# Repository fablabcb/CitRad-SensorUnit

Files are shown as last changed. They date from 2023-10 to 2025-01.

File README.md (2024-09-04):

# CitRad - Citizen Science Traffic Radar 

Here you find all the sources about how to build our traffic counter radar system. Find more about the project in general on our [project page](https://community.fablab-cottbus.de/t/ueber-das-cityradar-projekt/453). Discussions about the prototype development you find [here](https://community.fablab-cottbus.de/t/cityradar-teensy-prototyp/492/9). Also we have a separate discussion page about the [development of the casing](https://community.fablab-cottbus.de/t/gehaeusebau-fuer-die-radarsensorelektronik/507).

More details are in the [Software README]() and the [Hardware README](https://github.com/fablabcb/CityRadar/tree/main/Hardware#readme).

## Archive

In the beginning we started to develop a low noise amplifier for the radar module that we didn't need in the end. You find all about this in the [low-noise-amplifier branch](https://github.com/fablabcb/CityRadar/tree/low-noise-amplifier) and on the [discussion page in our forum](https://community.fablab-cottbus.de/t/citrad-elektronik-entwicklung/454)

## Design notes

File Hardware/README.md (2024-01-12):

# Bauanleitung Akkuvariante

## Teile

- Elektronik
  - [Teensy 4.0](https://www.pjrc.com/store/teensy40.html)
  - [Teensy Audio Board](https://www.pjrc.com/store/teensy3_audio.html)
  - [Innosent IPS-354 Radarmodul](https://www.innosent.de/radarsensoren/ips-354/) ([Handbuch](https://mm.digikey.com/Volume0/opasdata/d220001/medias/docus/2406/200730_Data%20Sheet_IPS-354_V1.5.pdf))
  - [isolierter DC-DC: ROE-3.305S](https://de.rs-online.com/web/p/dcdc-wandler/1392970)
  - [Akkupack](https://exp-tech.de/products/battery-lipo6600mah?_pos=33&_sid=1be852f75&_ss=r)
   - optional [TC4056](https://www.amazon.de/Aideepen-Lithium-Akku-Ladeplatine-Ladeger%C3%A4t-doppelten-Schutzfunktionen-Gr%C3%BCnes/dp/B0BZRT7Q6G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) Laderegler zum Laden der Batterie
  - SD-Karte nach Wahl
  - 40mm Kabel für Gnd des Radarmoduls
  - 40mm 2-Ader Kabel für Batteriestecker
  - Batteriestecker

- Gehäuse
  - [TRU COMPONENTS F3 Gehäuse](https://www.conrad.de/de/p/tru-components-f3-tc-6649456-universal-gehaeuse-115-x-90-x-55-abs-hellgrau-1-st-1662364.html)
  - [3D-Druck Halterung](https://community.fablab-cottbus.de/uploads/short-url/1HOEbMkdQxn1l1QFID4sH8OvwRe.stl)
  - [Lasercut Teile](https://community.fablab-cottbus.de/uploads/default/original/2X/0/07901a34dd58c6f2333bfa3191eb76f0abf1efdd.svg) zur Befestigung.
  - Velcro zur Befestigung des Akkus
  - Befestigungss  chrauben
    - 6x M4 für Einlegplatte und Seitenteile des Radarmoduls
    - 3x M3 für Befestigung der Platine

- Pfahlbefestigung
   - Lasercut Platte (enthält auch die Unterlegscheiben)
   - 4 x M5x10 für die Befestigungsplatte
   - 2x Velcro
   - 1x Kabelbinder

## Aufbau

### Platine vorbereiten

1. Teensy Vusb-Verbindung trennen (mit Messer). Danach einmal an USB anstecken und sicherstellen dass der Teensy nicht mehr von USB versorgt wird.
1. Knopfzellenbatterie an Teensy anlöten.
1. 14-Pin Pinleiste mit kurzer Seite in Audio Board einsetzen
1. Teensy auf die langen Stifte aufsetzen (Pins stehen über)
1. Pins auf der Audio Board Seite festlöten
1. von der Teensy Seite: 5V Pin und GND Pin (rechts und links vom USB) nach vorne biegen.
1. Batteriekabel an die überstehenden Pins von Gnd und 5V des Teensy löten.
1. Danach alle 14 Pins auch von der Teensy-Seite anlöten
1. Batteriestecker an Batteriekabel löten.
1. Die restlichen überlangen Pins können optional gekürzt werden.
1. DC-DC mit 3.3V und Gnd des Teensy verbinden (siehe Foto)
1. 6-Pin-Stecker mit langen Beinen anlöten:
    1. Pin 1 (Nummerierung wie am Radar-Modul) aus dem Stecker ziehen (wird nicht benötigt).
    1. Pin 5 und 6 umbiegen sodass sie in die line-in Anschlüsse des Audio Boards passen (siehe Foto).
    1. Enable (Pin 2) umbiegen und mit Pin 17 des Teensy verbinden (passt gerade so).
    1. Gnd (Pin 4) und Vcc (Pin 3) mit dem Output des DC-DC verbinden (siehe Foto). Hier muss man ca 4mm mit Lötzinn oder einem kurzen Draht überbrücken.
1. 4-Pin Stecker: GND (Pin 9) über kurzes Kabel mit Gnd am linein oder mic in verbinden.

### Radarmodul zusammen stecken

1. Radarmodul in 3D-Druck Halterung stecken (siehe Foto).
1. Teensy an 3D-Druck Halterung anschrauben (siehe Foto). Dabei die Stecker des Radarmoduls aufstecken.
1. 4-Pin Stecker am Radarmodul einstecken.
1. Lasercut Teile seitlich an das Radarmodul anschrauben.
1. SD-Karte in Audioboard einsetzen.

### Gehäuse vorbereiten

1. Grundplatte in Gehäuse schrauben.
1. Gewinde in Befestigungslöcher (Rückseite) schneiden.
1. Mastplatte mit M5-Schrauben und den Unterlegschrauben (im Lasercut Teil enthalten) an Rückseite anschrauben. 
1. Gummidichtung in Deckel einlegen (was zu lang ist abschneiden).

### Zusammenbau

1. Akku mit Kletterverschluss an Grundplatte befestigen.
1. Knopfzelle in Knopzellenhalter einsetzen.
1. Radarmodul mit Halterung in Schlitze in der Grundplatte stecken.
1. Teensy mit Batterie verbinden.

## Software installieren
1. Sketch drauf laden
2. Uhrzeit einstellen
3. Mit Processing überprüfen ob der Radarsensor richtig funktioniert

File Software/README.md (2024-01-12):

# Teensy Audio Board Prototype

This prototype works with the [IPS-354](https://media.digikey.com/pdf/Data%20Sheets/InnoSenT/200730_Data%20Sheet_IPS-354_V1.5.pdf) Radar Sensor from InnoSenT connected directly to the mic input of the [Teensy Audio Board](https://www.pjrc.com/store/teensy3_audio.html). The IPS-354 has a builtin gain of 27dB. The mic input of the audio board can regulate it's gain from 0 to 63dB. Together that's enough to detect cars, pedestrians and bicycles from the third floor of a building. When measured directly at the edge of the street the signal goes into clipping, so that the mic gain has to be set to about 55 to 58 dB. 

The teensy is programmed to continuously calculate a 1024 point FFT and transmit the data over Serial to the computer. The data are taken there by a [Processing](https://processing.org/) Script and visualized as a [waterfall diagram](https://en.wikipedia.org/wiki/Waterfall_plot). Additionally the Teensy calculates the frequency with highest amplitude which is optionally drawn as a line into the graph. This represents the mean speed of a moving object detected by the radar. 

The conversion from FFT bin to frequency is:

fft_bin_width = sample_rate/1024 = 44100 Hz/1024 = 43.0 Hz

The conversion from frequency to speed (at optimal angle, meaning the object comes directly onto the sensor) is:

speed = frequency/44

The Teensy also detects clipping with the `peak` function. If peak is returned as 1 the signal is in clipping. This is shown in the app as a green rectangle that turns red. With the <kbd>+</kbd> and <kbd>-</kbd> keys the gain can be regulated up or down to prevent clipping. Also the scale can be changed with the up and down arrows better see the lower speeds. You can also take a screenshot of the current view by pressing <kbd>s</kbd>.

Here a measurement done from 2m distance from the street edge. 

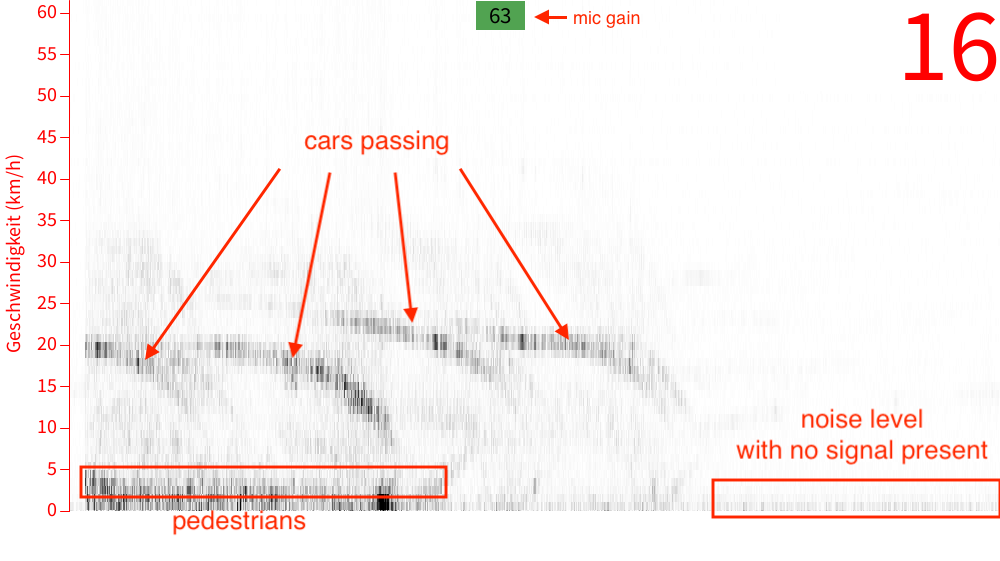
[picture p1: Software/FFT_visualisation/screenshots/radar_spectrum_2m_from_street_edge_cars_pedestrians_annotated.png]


Here a measurement with a pedestrian up close where arm and leg movement can be seen in the signal. Cars are on the opposite side of the street and hence with fainter signal:

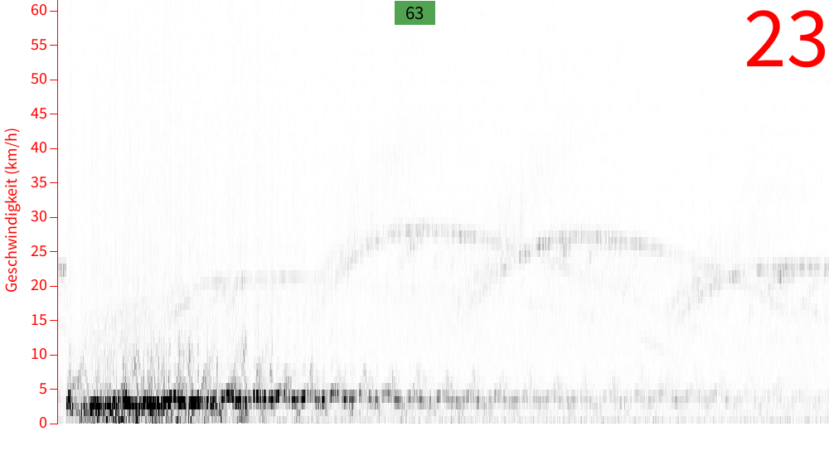
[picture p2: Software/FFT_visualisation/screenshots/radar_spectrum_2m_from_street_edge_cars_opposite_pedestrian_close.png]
pedestrian close


Here a measurement closer to the street with cars traveling both directions:	

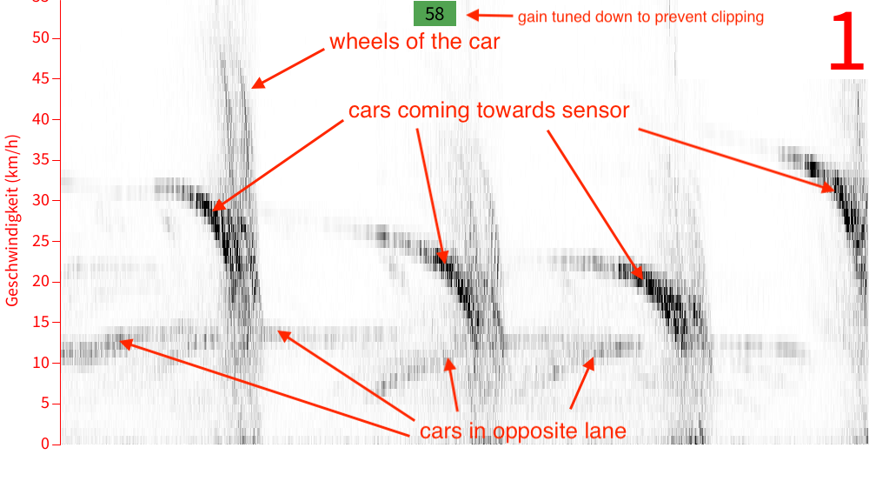
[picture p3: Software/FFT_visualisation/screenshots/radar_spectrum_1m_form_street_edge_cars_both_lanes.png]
cars both lanes


## Wiring

| IPS-354 | Audio Board | Teensy |
| --- | --- | --- |
| Pin 2 (enable) | - | Pin 22 |
| Pin 3 (Vcc) | - | Vcc |
| Pin 4 (Gnd) | Mic Gnd | Gnd |
| Pin 5 (signal I) | Mic | - |

## 32bit Audio Library

To get better input resulution we use a 32bit audio library that was forked from the original Teensy Audio library:

[OpenAudio_ArduinoLibrary](https://github.com/chipaudette/OpenAudio_ArduinoLibrary)

Similar to the original audio library it has a Design tool:

[OpenAudio_Design_Tool](http://www.janbob.com/electron/OpenAudio_Design_Tool/index.html)

## Serial

The teensy opens two serial connections over usb. The first one `Serial` is used for data transmission to the processing visualisation script. 
The second one `SerialUSB1` is used for debugging.

It is important to set the Arduino IDE to dual serial: "Tools > USB Type: Dual Serial".

More infos under https://github.com/TeensyUser/doc/wiki/Serial and https://www.pjrc.com/teensy/td_serial.html

## IQ FFT

The 32bit audio library supports complex FFT calculation with I and Q channel. The [IPS-354](https://media.digikey.com/pdf/Data%20Sheets/InnoSenT/200730_Data%20Sheet_IPS-354_V1.5.pdf) sends 
I and Q signals from which the direction of the radar signal can be derived. To record I and Q signal we have to use the linein input instead of the mic input. This has only 0-22dB gain 
instead of up to 63dB gain on the mic input. But it offers two channels that we need for the IQ signal. The input sensitivity seems enough for the IPS-354.

We have done a correction for I-Q imbalance after [this instruction](https://www.faculty.ece.vt.edu/swe/argus/iqbal.pdf).

We develop this type of data analysis in the [IQ-fft branch](https://github.com/fablabcb/CityRadar/tree/IQ-fft/Teensy_prototype). 

The wiring is as follows:

| IPS-354 | Audio Board | Teensy |
| --- | --- | --- |
| Pin 2 (enable) | - | Pin 22 |
| Pin 3 (Vcc) | - | Vcc |
| Pin 4 (Gnd) | Linein Gnd L| Gnd |
| Pin 5 (signal I) | Linein L | - |
| Pin 6 (signal Q) | Linein R | - |

## Writing to SD card

The program writes FFT data to the SD card (if present). The format is one 32bit unsigned integer timestamp in milliseconds since the start of the program
followed by 1024 times 32bit floats of the FFT bins in dBFS. This repeats for as long as the program was running.

At the beginning there is a file header containing:

- file_version (uint 2 bytes)
- timestamp (uint 4 bytes)
- fft_bins (uint 2 bytes)
- iq_measurement (bool 1 byte)
- sample_rate (uint 2 bytes)

In general every 12 milliseconds one dataset is written. Sometimes there seem to be hookups where there is longer times between datasets (up to 100 milliseconds).

The file `read_binary_file.R` shows how to read this dataset into R.

### SD noise problems

At the moment writing to SD creates noise in the data.

Some ideas how to tackle this:

- Some ideas from here: [How-to-avoid-noise-when-writing-to-the-microSD](https://forum.pjrc.com/threads/25326-How-to-avoid-noise-when-writing-to-the-microSD)
- change main clock speed -> didn't improve noise
- change slew rate of the pins: https://www.pjrc.com/teensy/IMXRT1060RM_rev2.pdf#page=695 with `IOMUXC_SW_PAD_CTL_PAD_GPIO_B0_00 = 0b0000'0000'0000'0000'0001'0000'1011'0000;`
- add condensators to buffer high Vcc demands
  - 10kOhm to buffer sensor input voltage didn't help
- use SD card of Teensy 4.1 instead of the audioshield. This itself doesn't improve. But maybe the SD pins to the audioboard should not be connected?
- pause data aquisition while writing to SD

## Real time clock

To add correct timestamps to the stored data we use the internal real time clock (RTC) of the Teensy. A coin cell battery needs to be connected to the VBat input 
to keep the internal RTC running. More on this here: [Teensy Time library explanation and examples](https://www.pjrc.com/teensy/td_libs_Time.html).

The Teensy uses the [Arduino time library](https://playground.arduino.cc/Code/Time/). 
Since at 44100 kHz we get a 1024 point FFT every 12 milliseconds a sub-second time resolution is needed.
The [millis function](https://www.arduino.cc/reference/en/language/functions/time/millis/) gives back milliseconds since start of the processor and can
complement the timestamp from the Time library. 

TimeSerial example under `File > Examples > Time > TimeSerial` shows how to set the rtc time via serial input.
Here is a forum Thread on [how to access the internal RTC in a Teensy 4.0](https://forum.pjrc.com/threads/60317-How-to-access-the-internal-RTC-in-a-Teensy-4-0).

From the Linux command line you can set the clock on the Teensy with:

```
date -u +T%s > /dev/ttyACM0
```
The command sends the letter "T" followed by the current time. Replace `ttyACM0` with your serial device name. 
`-u` sets the time as [Unix time](https://en.wikipedia.org/wiki/Unix_time).

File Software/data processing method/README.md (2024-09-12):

# CitRad Radar Sensor data processing method

We use R to prototype and test the data processing later to be implemented on the sensor unit itself. 

## Setup R environment:

Install R from [r-project.org](https://www.r-project.org/). Also we suggest using the [RStudio IDE](https://posit.co/downloads/).

Open the project by opening the `.Rproj` file in RStudio.

We use [renv](https://rstudio.github.io/renv/index.html) to keep track of package versions. Execute `renv::restore()` to install all packages recorded in `renv.lock`. Maybe you have to install renv first with `install.packages("renv")`.

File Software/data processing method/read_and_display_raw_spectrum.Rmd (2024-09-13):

---
title: CitRad - read and display raw spectrum data
---

```{r knitr settings, echo=F, include=F}
knitr::opts_chunk$set(echo=T, cache=F, warning =F, message = F, error = F)
```

Load the necessary libraries:

```{r libraries and helper functions}
library(plyr)
library(dplyr)
library(viridis)
library(lubridate)
source("functions.R")
```

## read data

To read the raw data use the `read_binary_file_8bit()` function located in `functions.R`. 

```{r read data, results='hide'}
filename <- "../../../data/SD-Card/2024-03-29_Nordring/rawdata_2024-3-29_12-8-50.BIN"
data_list <- read_binary_file_8bit(filename)
#rm(data, file_version, iq_measurement, n, num_fft_bins, size, start_time, timestamps, sample_rate)
attach(data_list)
```

The `attach()` command puts all variables in data_list in the global environment.

## conversion between frequency and speed

The FFT bins go from 1 to 1024. Bin 512 is 0 km/h. The upper bins represent positive speeds, lower bins negative speed (movement in the opposite direction). The conversion factor between frequency and speed is the following:

$$\frac{sample\_rate}{1024}/44.0 \approx 0.266$$
with $sample\_rate = `r sample_rate`$

```{r speed conversion, echo=T}
speed_conversion = (sample_rate/1024)/44.0
speeds <- (1:1024-512) * speed_conversion
```

In preparation for the plots we also do some timestamp conversion:

```{r timestamp conversion}
timestamps_date <- start_time + milliseconds(timestamps)
timestamp_minutes = timestamps/1000/60
```

# plot spectrum

```{r plot with timestamp}
index <- 19585+0:1000
image(timestamp_minutes[index], speeds,  data[index,], col=magma(100), main="spectrum")
```

To speed up the generation of the spectrum plot (especially for large timeframes) we can use the option `useRaster = T`:

```{r plot faster with index}
image(index, speeds,  data[index,], col=magma(100), useRaster = T, main="spectrum")
```

Since `useRaster` needs a regular x-axis we can't use the timestamp, since that one is a bit irregular depending on the processing speed of the Teensy:

```{r timestamp irregularities}
diff(timestamps) %>% unique %>% sort
```

To add back some sensible x-axis:

```{r plot with tick labels}
tick_positions <- seq(min(index), max(index), length.out=10)
tick_labels <- (start_time + minutes(round(timestamp_minutes[tick_positions]))) %>% with_tz("CET") %>%
  format("%Y-%m-%d\n%H:%M:%S %Z") %>% paste(., "\n", round(tick_positions))

image(index, speeds,  data[index,], col=magma(100), useRaster = T, xaxt="n", xlab="", main="spectrum")
axis(1, tick_positions, tick_labels, mgp=c(4, 2.5, 0))
```

We can also limit the speeds to the expected range and add some grid lines:

```{r speed selection and grid lines}
speed_selection <- which(abs(speeds)<=70)
image(index, speeds[speed_selection],  data[index,speed_selection], col=magma(100), useRaster = T, xaxt="n", xlab="", main="spectrum")
axis(1, tick_positions, tick_labels, mgp=c(4, 2.5, 0))
abline(h=-7:7*10)
```

# write plot to file:

We create a graphics folder first:

```{r create graphics folder}
dir.create("Grafiken")
```

And then render a graphic for the whole timeline into a png file:

```{r export png}
system.time({ # tells us the processing time it took
  
# calculate pixel width with 200 pixels per minute:
timerange_minutes <- diff(range(timestamp_minutes))
pixel_width <-  round(timerange_minutes) * 200

# pepare axis with 1 tick per minute:
index <- 1:length(timestamps)
tick_positions <- seq(min(index), max(index), length.out=timerange_minutes)
tick_labels <- (start_time + minutes(round(timestamp_minutes[tick_positions]))) %>% with_tz("CET") %>%
  format("%Y-%m-%d\n%H:%M:%S %Z") %>% paste(., "\n", round(tick_positions))

filename = paste0("./Grafiken/", as.numeric(Sys.time()), ".png")
# open graphic device:
png(filename, height = 500, width = pixel_width)

# create graphic
image(index, speeds[speed_selection],  data[index,speed_selection], col=magma(100), useRaster = T, xaxt="n", xlab="", main="spectrum")
axis(1, tick_positions, tick_labels, mgp=c(4, 2.5, 0))
abline(h=-7:7*10)

# close graphic device
dev.off()

})
```

In my experience the fastest way to display big spectrum image files is in the browser (like Firefox or Chrome).

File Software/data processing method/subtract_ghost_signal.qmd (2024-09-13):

---
title: Citrad - tests to subtract ghost signal
format: 
  revealjs:
    css: style.css
    auto-stretch: false
    
output: 
  revealjs::revealjs_presentation:
    code_folding: hide
---

## ghost signal

Whenever the sensor detects a forward signal it also detects a signal in the opposite direction. Mirroring and subtracting the spectrum is one approach to deal with this. It seemed to work for the measurements we made at BTU location. But doesn't work at the Nordring location. There might be differences in the Q-I balance settings between those measurements. This has still to be validated.

```{r knitr settings, echo=T, include=F}
knitr::opts_chunk$set(echo=F, cache=F, warning =F, message = F, error = F)
```

```{r libraries}
library(plyr)
library(dplyr)
library(dygraphs)
library(viridis)
library(lubridate)

source("functions.R")
```

# BTU

```{r read BTU data, results="hide"}
filename <- "../../../data/SD-Card/2023-12-07/rawdata_2023-12-6_19-41-12.BIN"
data_list <- read_binary_file_8bit(filename)
attach(data_list)
timestamps_date <- start_time + milliseconds(timestamps)
timestamp_minutes = timestamps/1000/60
speed_conversion = (sample_rate/1024)/44.0
speeds <- (1:1024-512) * speed_conversion
```

## spectrum

```{r BTU plot with different subtractions, fig.subcap="The signal looks mirrored around 0, but the ghost signal on the opposite side is a bit weaker. This timeframe actually contains 3 Targets (one in opposite direction)."}
s = 971000
index <- 971000 + 0:1000

image(index, speeds,  data[index,], col=magma(100), useRaster = T, family="Arial")
```

## spectrum - 50% mirror

```{r BTU plot with different subtractions 2, fig.subcap="Subtracting 50% of the mirrored spectrum removes a lot of the oscillating noise patterns and some of the ghost reverse signals."}
image(index, speeds,  data[index,]-.5*data[index,c(1023:1,1)], col=magma(100), useRaster = T, family="Arial")
```

## spectrum - 100% mirror

```{r BTU plot with different subtractions 3, fig.subcap="This seems to remove nearly all noise. The ghost signal now has negative values. Additionally the line around 0 km/h disappears and values are around 0."}
image(index, speeds,  data[index,]-1*data[index,c(1023:1,1)], col=magma(100), useRaster = T, family="Arial")
```

## spectrum - 100% mirror, <0 set to 0

```{r BTU plot with different subtractions 4, fig.subcap="Removing all negative values leaves only the signal clearly highlighted. But some noise spikes are pretty bright."}
mirror_subtracted <- (data[index,]-1*data[index,c(1023:1,1)])

mirror_subtracted[mirror_subtracted<0] = 0

image(index, speeds, mirror_subtracted , col=magma(100), zlim=c(0,30), useRaster = T, family="Arial")
```

```{r BTU export png, eval=F, echo=F}
system.time({ # tells us the processing time it took
  
index <- 4*226104+1:226104
# calculate pixel width with 200 pixels per minute:
timerange_minutes <- diff(range(timestamp_minutes[index]))
pixel_width <-  round(timerange_minutes) * 200

# pepare axis with 1 tick per minute:
tick_positions <- seq(min(index), max(index), length.out=timerange_minutes)
tick_labels <- (start_time + minutes(round(timestamp_minutes[tick_positions]))) %>% with_tz("CET") %>%
  format("%Y-%m-%d\n%H:%M:%S %Z") %>% paste(., "\n", round(tick_positions))

speed_selection <- which(abs(speeds)<=70)

filename = paste0("./Grafiken/BTU_", as.numeric(Sys.time()), ".png")
# open graphic device:
png(filename, height = 500, width = pixel_width)

# create graphic
image(index, speeds,  data[index,] - data[index,c(1023:1,1)], col=magma(100), useRaster = T, xaxt="n", xlab="", main="BTU")
axis(1, tick_positions, tick_labels, mgp=c(4, 2.5, 0))
#abline(h=-7:7*10)

# close graphic device
dev.off()

})
```

```{r, echo=F}
detach(data_list)
rm(data_list)
```

# Nordring

```{r read Nordring data, results="hide"}
filename <- "../../../data/SD-Card/2024-03-29_Nordring/rawdata_2024-3-29_12-8-50.BIN"
data_list <- read_binary_file_8bit(filename)
#rm(data, file_version, iq_measurement, n, num_fft_bins, size, start_time, timestamps, sample_rate)
attach(data_list)
timestamps_date <- start_time + milliseconds(timestamps)
timestamp_minutes = timestamps/1000/60
```

```{r calc speeds}
speed_conversion = (sample_rate/1024)/44.0
speeds <- (1:1024-512) * speed_conversion
```

## spectrum

```{r Nordring plot with different subtractions, fig.subcap="Multiple targets in this time window."}
index <- 19585+0:1000
spectrum_mirror_subtracted <- data[index,] - .5*data[index,c(1023:1,1)]

image(index, speeds,  data[index,], col=magma(100), useRaster = T)
```

## spectrum - 50% mirrored

```{r Nordring plot with different subtractions2, fig.subcap="Subtracting with 50% of the mirrored spectrum removes some of the ghost reverse signals, but also makes the real signal weaker in relation to the noise (noise gets brigther)."}
image(index, speeds,  spectrum_mirror_subtracted, col=magma(100), useRaster = T)
```

## spectrum - 100% mirrored

```{r Nordring plot with different subtractions3, fig.subcap="Subtracting with 100% of the mirrored spectrum hides the signal completely."}
spectrum_mirror_subtracted <- data[index,] - 1*data[index,c(1023:1,1)]
image(index, speeds,  spectrum_mirror_subtracted, col=magma(100), useRaster = T)
```

## spectrum - 100% mirrored, < 0 set to 0

```{r Nordring plot with different subtractions4, fig.subcap="no signal visible"}
spectrum_mirror_subtracted <- data[index,] - 1*data[index,c(1023:1,1)]
spectrum_mirror_subtracted[spectrum_mirror_subtracted<0] = 0
image(index, speeds,  spectrum_mirror_subtracted, col=magma(100), useRaster = T)
```

```{r Nordring export png, eval=F, echo=F}
system.time({ # tells us the processing time it took
  
# calculate pixel width with 200 pixels per minute:
timerange_minutes <- diff(range(timestamp_minutes))
pixel_width <-  round(timerange_minutes) * 200

# pepare axis with 1 tick per minute:
index <- 1:length(timestamps)
tick_positions <- seq(min(index), max(index), length.out=timerange_minutes)
tick_labels <- (start_time + minutes(round(timestamp_minutes[tick_positions]))) %>% with_tz("CET") %>%
  format("%Y-%m-%d\n%H:%M:%S %Z") %>% paste(., "\n", round(tick_positions))

filename = paste0("./Grafiken/Nordring_", as.numeric(Sys.time()), ".png")
# open graphic device:
png(filename, height = 500, width = pixel_width)

# create graphic
image(index, speeds,  data[index,], col=magma(100), useRaster = T, xaxt="n", xlab="", main="Nordring")
axis(1, tick_positions, tick_labels, mgp=c(4, 2.5, 0))
#abline(h=-7:7*10)

# close graphic device
dev.off()

})
```

```{r detach, results="hide"}
detach(data_list)
rm(data_list)
```

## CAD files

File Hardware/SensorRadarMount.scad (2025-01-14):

mainH = 12; // main body height
mainD = 45.9; // main body depth
mainW = 17.78 * 2; // main body width
roundingD = 6; // depth of the front/back rounding thingy
roundingHoleD = 2.8; // diameter of the back/front holes

sensorD = 44.3; // outer depth of the sensor plate
sensorW = 30.3; // outer width of the sensor plate
sensorFullSizeH = 3; // depth of the cutout for the sensor plate
sensorLipW = 1; // width of the lip for the sensor to rest on
sensorFullH = sensorFullSizeH + 6; // depth of the entire sensor cutout

smallSlotW = 12; // width of the small slot
smallSlotX = 10.5; // x offset (from outer edge)
bigSlotW = 17; // width of the big slot
bigSlotX = 8; // x offset (from outer edge)
sensorSlotD = 4; // depth of the header slots for the sensors

$fn=50;
e=0.01;

// xz-origin: center of the hole
module SideThingy()
{
    difference()
    {
        union()
        {
            cube([mainW/2,roundingD,mainH]);
            translate([0,0,mainH/2]) rotate([-90,0,0]) cylinder(d=mainH, h=roundingD);
        }
        
        translate([0,0,mainH/2]) rotate([-90,0,0]) cylinder(d=roundingHoleD, h=roundingD+e);
    }
}

module CompleteHolder()
{
    translate([0,-mainD/2,0]) difference() 
    {
        // main body
        cube([mainW, mainD, mainH]);
        // flat sensor part cutoff
        translate([1.36,(mainD-sensorD)/2,0]) cube([sensorW, sensorD, sensorFullSizeH]);
        // round sensor part cutoff
        translate([1.36+sensorLipW,(mainD-sensorD)/2+sensorLipW,0])
            cube([sensorW-2*sensorLipW, sensorD-2*sensorLipW, sensorFullH]);
        
        // small header slot
        translate([smallSlotX,sensorLipW+sensorD-sensorSlotD,-1]) cube([smallSlotW,sensorSlotD,99*mainH]);
        // big slot and push-through area
        translate([bigSlotX,sensorLipW,-1]) cube([bigSlotW,sensorD-10-sensorSlotD,99*mainH]);
        // holes
        hR=1.4;
        holes=[[1.9+hR,5.8+hR],[mainW-1.9-hR,5.8+hR],[14.6+hR,mainD-7.07-hR]];
        for(h=holes)
            translate([h[0],h[1],mainH-3]) cylinder(r=1.4, h=3+e);
        // groves for teensy pins
        for(y=[12.8,12.8+15.24])
            translate([0,y,mainH]) rotate([0,90,0]) cylinder(r=2, h=mainW, $fn=7);
        
        translate([mainW*0.73,mainD/2-5,mainH-1]) linear_extrude(1) text("v2",size=6);
    }
    
    translate([mainW/2,0,0])
    {
        translate([0,mainD/2,0]) SideThingy();
        mirror([0,1,0])
            translate([0,mainD/2,0]) SideThingy();
    }
}

CompleteHolder();

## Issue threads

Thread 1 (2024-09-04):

Auswertemethode erklären/dokumentieren

nFrechen, 2024-09-04:
Ich habe die bisherige Auswertemethode in R schon halb dokumentiert und mit Grafiken nachvollziehbar gemacht. Das müsste ich noch zu Ende bringen und die Verständlichkeit testen.

nFrechen, 2024-09-12:
In einem ersten Schritt habe ich dokumentiert wie man die Rohdaten einliest und das Spektrum mit R visualisiert: #[8b3c7b8](https://github.com/fablabcb/CitRad-SensorUnit/commit/8b3c7b8aca13ac50723f8f669568a57b6cc04ff8)

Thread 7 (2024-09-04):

kleinere Raw-Dateien schreiben

nFrechen, 2024-09-04:
z.B. Stündlich neue Dateien anlegen damit man keine 4GB Dateien einlesen muss

thorondev, 2024-09-22:
Nach je einer Stunde wird nun eine neue Datei geöffnet.

nFrechen, 2024-10-28:
Die start_time wird in die Datei geschreiben aber die millis werden nicht zurück gesetzt beim Erstellen einer neuen Datei. Wenn man nun versucht die Zeit zu rekonstruieren als start_time + millis hat man einen Zeitversatz.

nFrechen, 2024-10-28:
Ok, kann man beheben indem man den ersten gespeicherten millisecond Wert von allen Zeitstempeln abzieht.

thorondev, 2024-10-30:
Ja, das ist immer die Zeit, seit der der Sensor läuft und damit muss man das sowieso immer machen, um auf die korrekte Zeit zu kommen. Da die Datei erst angelegt wird, wenn der erste Datensatz geschrieben wird, entspricht der erste Zeitstempel der Erstellzeit der Datei.

Closed 2025-01-03.

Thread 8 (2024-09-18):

low battery detection

nFrechen, 2024-09-18:
Problem:

wenn die Akkuspannung niedrig ist geht der Teensy irgendwann aus, startet aber eventuell mehrmals nochmal neu wenn die Akkuspannung sich regeneriert (z.B. durch Temperaturschwankungen). Ergebnis: mehrere kleine Dateien mit neuen Messungen. Eventuell kann auch die SD-Karte kaputt gehen wenn der Teensy immer wieder startet.

Idee:

Batteriespannung messen und beim boot testen ob Spannung zu niedrig und in deep-sleep gehen.

thorondev, 2025-01-03:
Ich habe z.B. das hier gefunden, aber das übersteigt meine Elektronikkentnisse: https://forum.pjrc.com/index.php?threads/how-measure-battery-voltage.43430/

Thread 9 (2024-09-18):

Dateinamen (Zeitstempel) wenn RTC nicht arbeitet

nFrechen, 2024-09-18:
Wenn die RTC versagt (oder die Knopfzelle nicht drin ist) und der Teensy von "Tag 0" startet, wie vermeidet man dass Dateien überschrieben werden?

Idee:

Dateien durchnummerieren (d.h. checken ob schon andere Dateien da sind).

Closed 2024-09-22.

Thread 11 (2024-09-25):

smoothing

nFrechen, 2024-09-25:
Ich muss hier nochmal was meine Gedanken sortieren:

In der Auswertung werden wir an mehreren Stellen eine Glättung der Messwerte brauchen. Ein laufendes Mittel können wir mit drei verschiedenen Komplexitätsstufen umsetzen:

## 1. vereinfachtes Mittel

`runmean[i] = ((n-1) * runmean[i-1] + x[i])/n`

Hier braucht man keinen Array mit Werten vorhalten, sondern nur das letzte Mittel `runmean[i-1]`. Der neue Messwert `x[i]` wird auf das letzte Mittel drauf gerechnet mit einer Gewichtung (z.B. 1) während das vorige Mittel mit Gewichtung 99 eingeht. Zum Schluss wird alles durch n=100 geteilt.

Diese Berechnung ist mathematisch nicht 100% korrekt, da der Einfluss früher Werte nie ganz aus dem Mittelwert verschwindet. Allerdings funktioniert es ausreichend gut. Nachteil ist aber, dass die Methode nicht symmetrisch arbeitet.

## 2. echtes laufendes Mittel aber ohne bzw. mit Rechteck-Kernel

Hier muss ein Array aus Werten mitgeführt werden (z.B. die letzen 100 Werte). Jeder neue Messwert wird dem Array hinzugefügt während der älteste Wert aus dem Array gelöscht wird. Anschließend wird der Mittelwert über das Array berechnet. Da die Werte im Array nicht gewichtet werden (ohne Kernel), kann das Array als Ringspeicher geführt werden. Es wird also immer der älteste Wert mit dem neuesten überschrieben ohne die anderen Werte anzufassen.

Alle Werte mit gleicher Wichtung in das gleitende Mittel eingehen zu lassen entspricht einem Rechteck-Kernel. Durch den Rechteck-Kernel kann das Ergebnis immer noch scharfe Sprünge aufweisen, auch wenn die Amplitude abgeschwächt wird. Der Rechteck-Kernel bewirkt auch dass Peaks zu Plateaus ohne definierte Spitze werden. Das ist ungünstig wenn man die Spitze finden möchte. Daher die dritte Methode:

## 3. laufendes Mittel mit Gauß-Kernel

Wenn man die Mittelwert-Berechnung noch mit einer Gewichtung machen möchte (z.B. ein Gauß-Kernel), ist die Reihenfolge der Werte im Array relevant. Hier könnte man trotzdem noch mit einem Ringspeicher arbeiten, wenn man den Kernel entsprechend verschiebt. Ansonsten muss man mit jedem neuen Eintrag die anderen Werte im Array in ihrer Position nach vorne schieben.

Der Gauß-Kernel bewirkt dass Werte am Rande des Glättungsfensters weniger Einfluss auf den Mittelwert haben. Dadurch bekommt alles einen smoothen Übergang.  Der Gauß-Kernel erhält aber trotzdem größere Peaks die in den Daten enthalten sind.

thorondev, 2024-10-30:
Wir haben uns jetzt auf ein Hann-Fenster verständigt und das ist implementiert. Damit kann das hier geschlossen werden

Closed 2025-01-03.

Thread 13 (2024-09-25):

Gauß Kernel Glättung

nFrechen, 2024-09-25:
Für die Auto-Trigger-Berechnung brauche ich eine Glättung die zeitlich symmetrisch ist, also genauso viel Werte aus der Vergangenheit wie aus der Zukunft verrechnet. D.h man müsste n Werte als Array vorhalten und die Berechnung erst machen wenn n Werte aufgezeichnet wurden. Das Ergebnis kann man dann erst speichern wenn genug Werte aufgelaufen sind mit dem Zeitstempel um (n-1)/2 versetzt.  Von daher müsste  man das eventuell in eine zweite csv-Datei speichern oder in der schon existierenden CSV-Datei kenntlich machen dass der Wert um (n-1)/2 zeitlich verschoben ist.

$$w(i)=e^{-\frac{1}{2} \left ( \frac{i-(n-1)/2}{\sigma (n-1)/2} \right)^{2}}$$

mit $\sigma = 1/4$.
$i$ ist der index im Fenster.

n konfigurierbar. Im Moment rechne ich mit n=31. Nur ungerades n verwenden.

Das Fenster müsste man beim booten vorberechnen können und dann als Array vorhalten.

Wir hatten darüber diskutiert wie man das ganze mit einem Ringspeicher umsetzen kann.

Ergebnis als `car_trigger_signal` benennen. Eingabewert n als `car_trigger_signal_smoothing_factor` konfigurierbar machen.

nFrechen, 2024-09-25:
Noch besser wäre das [Hann-Fenster](https://de.wikipedia.org/wiki/Fensterfunktion#von-Hann-Fenster)

$$ w(i)={\frac {1}{2}}\left[1-\cos \left({\frac {2\pi i}{n-1}}\right)\right]$$

thorondev, 2024-10-01:
Config Value: "carTriggerSignalSmoothingFactor"

thorondev, 2024-10-01:
csv headers for new outputs (car_trigger_signal and dynamic_noise_level) now contain the N as a suffix.

Closed 2024-10-01.

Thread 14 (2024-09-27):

weitere Datenauswertung

nFrechen, 2024-09-27:
Ich habe die Auswertemethode nun in [Software/data processing method/data_processing_method.Rmd](https://github.com/fablabcb/CitRad-SensorUnit/blob/main/Software/data%20processing%20method/data_processing_method.Rmd) beschrieben.

Zu beachten in R:

- Der Array Index beginnt bei 1 und nicht bei 0
- Wenn `v` ein Vektor ist dann  kann man in R `v*2` rechnen, wodurch jedes Element im Array mit 2 multipliziert wird. Genauso kann man die Elemente von zwei gleich langen Vektoren Element zu Element miteinander verrechnen mit `v*w`. Man braucht hier also keine Schleife.
- `apply` Funktionen arbeiten ähnlich wie `map` Funktionen in anderen Sprachen. Damit kann man z.B. eine Matrix in Zeilen zerschneiden und eine Funktion auf jede Zeile anwenden.

Am besten gehen wir gemeinsam durch den Code und überlegen wie wir das Stück für Stück umsetzen können.

thorondev, 2024-10-30:
Aktueller Stand liegt auf dem Develop.

Closed 2024-10-30.

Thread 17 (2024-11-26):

timestamp Sprünge

nFrechen, 2024-11-26:
Der Zeitstempel in den Rohdaten zeigt manchmal Sprünge. Auf jeden Fall immer dann wenn intensiv gerechnet wird. Manchmal aber auch zwischendurch. Die Sprünge zwischendurch korrelieren mit Störsignalen die im Spektrum zu sehen sind (siehe Grafik unten). Das kann gut sein dass der Teensy da irgendwas macht was sowohl das Störsignal wie auch die Zeitverzögerung erzeugt. Ist die Frage ob man da rauskriegen kann was da passiert. Wenn das Störsignal im Spektrum verschwindet wäre schon gut.

Zu den rechen- bzw. schreibintensiven Zeiten könnte man vielleicht den Zeitstempel direkt generieren wenn die Daten von der FFT übernommen werden und nicht erst am Ende der Berechnung. Ich hab mir noch nicht angeschaut wie das zur Zeit umgesetzt ist.

Die Schwarze Linie ist die Zeitdifferenz zwischen zwei Zeitstempeln (in Millisekunden). Oft sieht es aus als würde der längere Zeitabstand durch einen entsprechend kürzeren ausgeglichen. Manchmal aber auch nicht.
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

thorondev, 2024-11-26:
Der Zeitstempel wird bisher tatsächlich nach der Berechnung ermittelt. Das ist natürlich etwas ungünstig und kann ich ändern. Ansonsten sehe ich in den Sprüngen kein größeres Problem.

nFrechen, 2024-11-27:
Dann kannst du den Zeitstempel ja direkt nach der FFT speichern. Das wäre ja eine einfache Maßnahme.

Das mit dem regelmäßigen Störsignal kriegt man wahrscheinlich nicht so leicht raus warum das passiert. Das wäre eher interessant wegen dem Störsignal selbst und nicht wegen dem Zeitversatz. Der Zeitversatz ist nur ein Hinweis darauf dass der Teensy da irgendwas rechnet was ihn aufhält.

Das Thema kommt auf weil ich mich gerade damit beschäftige wie man noch die Fahrzeuglänge aus dem Signal berechnen kann. Da wäre ein Zeitversatz im Signal ungünstig. Aber ich hab bisher auch nur grobe Ideen dazu. Vielleicht ist es auch kein Problem.

thorondev, 2025-01-03:
fixed in 9f67bfd804535d440e483ddbcd22a1cdf3078162

Closed 2025-01-03.

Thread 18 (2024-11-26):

Zeitstempel Versatz zwischen csv- (car) und bin-Datei

nFrechen, 2024-11-26:
Wenn ich die Zeitstempel aus der cars csv Datei einlese und diesen Zeistempel nutze um das Spektrum aus der bin Datei abzufragen komme ich nicht exakt zu dem Zeitpunkt wo das Auto vorbei gefahren ist. Der Zeitvesatz ist manchmal länger, manchmal kürzer (siehe Beispiele unten).

Der Abstand variiert auch innerhalb einer Datei. Von daher denke ich nicht dass ich da was falsch einlese.

Hast du eine Idee woher das kommen könnte?

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

thorondev, 2024-11-26:
Der Zeitstempel in der Car-CSV gibt an, wann das Signal als ein Auto erkannt wurde und nicht, wann genau ein Peak in der meanAmplitude vorlag.

Du kannst auf jeden Fall also schonmal die Hann-Fensterbreite abziehen, weil das ja später erst ausgewertet werden kann. Und dann ist natürlich jedes Signal unterschiedlich lang - das fließt auch wieder mit ein.
Wenn du die Zuordnung tatsächlich brauchst, muss das hinzugefügt werden. Der Sensor merkt sich die vergangenen Zeitstempel bisher nicht.

thorondev, 2025-01-07:
Mit Dateiversion 3 ist der Zeitstempel Car-CSV-Datei nicht länger der Zeitpunkt, wann die Erkennung gespeichert wurde, sondern wann das Trigger-Signal in den Daten erkannt wurde. Damit kann man jetzt den Zeitstempel suchen, die Hann-Fensterbreite abziehen und ist an der richtigen Position.

thorondev, 2025-02-03:
Mit Dateiversion 4 ist im Header jeweils ein TimeOffset vorhanden. Siehe FileFormats.md.

Closed 2025-02-03.

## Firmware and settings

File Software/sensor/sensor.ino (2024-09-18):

#include "AudioSystem.h"
#include "Config.h"
#include "FileWriter.hpp"
#include "SerialIO.hpp"
#include "functions.h"

#include <SerialFlash.h>
#include <Wire.h>
#include <utility/imxrt_hw.h>

AudioSystem audio;
AudioSystem::Results audioResults; // global to optimize for speed
Config config;

FileWriter fileWriter;
SerialIO serialIO;

bool canWriteData = false;

void setup()
{
    setSyncProvider(getTeensy3Time);
    setI2SFreq(config.audio.sample_rate);

    // TODO maybe move to audio
    pinMode(PIN_A3, OUTPUT); // A3=17, A8=22, A4=18
    digitalWrite(PIN_A4, LOW);

    audio.setup(config.audio, config.max_pedestrian_speed, config.send_max_speed);

    // TODO this seems to be a get&set to and from the same data point?
    // setTime(Teensy3Clock.get());
    // timestamp = now();
    {
        time_t timestamp = Teensy3Clock.get();
        setTime(timestamp);
    }

    // wait max 5s for serial connection
    {
        Serial.begin(9600);
        int counter = 5;
        while(counter > 0 && !Serial)
        {
            delay(1000);
            counter--;
        }
        Serial.println("Hello Citizen Radar");
    }

    fileWriter.setupSpi();

    if(fileWriter.setupSdCard())
    {
        canWriteData = true;
        Serial.println("SD card initialized");
    }
    else
        Serial.println("Unable to access the SD card");
}

void loop()
{
    if(not canWriteData)
    {
        if(fileWriter.setupSdCard())
        {
            canWriteData = true;
            Serial.println("SD card initialized");
        }

        delay(1000);
        return;
    }

    if(not audio.hasData())
    {
        delay(1);
        return;
    }

    bool sendOutput = false; // send output over serial - attention: this is only send once and needs to be preserved
    // and thus might be better put into global state or something

    serialIO.processInputs(config.audio, sendOutput);
    if(config.audio.hasChanges)
    {
        audio.updateIQ(config.audio);
        config.audio.hasChanges = false;
    }

    // elapsed time since start of sensor in milliseconds
    audioResults.timestamp = millis();
    audio.processData(audioResults);

    if(config.writeDataToSdCard)
    {
        if(config.writeRawData)
            fileWriter.writeRawData(audioResults, config.write8bit, config);

        if(config.writeCsvData)
            fileWriter.writeCsvData(audioResults, config);

        // SerialUSB1.print("csv sd write time: ");
        // SerialUSB1.println(millis()-time_millis);
    }

    if(sendOutput)
        serialIO.sendOutput(audioResults, audio, config);
}

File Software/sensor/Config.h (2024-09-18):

#ifndef CONFIG_H
#define CONFIG_H

#include "AudioSystem.h"

#include <cstddef>
#include <string>

struct Config
{
    AudioSystem::Config audio;

    const float max_pedestrian_speed = 10.0; // m/s; speed under which signals are detected as pedestrians
    const float send_max_speed = 500;        // don't send (and store) spectral data higher than this speed
    const float TRIGGER_AMPLITUDE = 100;     // trigger threshold for mean amplitude to signify a car passing by
    const long COOL_DOWN_PERIOD = 1000;      // cool down period for trigger signal in milliseconds

    const bool writeDataToSdCard = true; // write data to SD card?
    const bool write8bit = true;         // write data as 8bit binary (to save disk space)
    const bool writeRawData = true;      // write raw spectral data to SD?
    const bool writeCsvData = true;      // write calculated metrix to csv table?

    const bool splitLargeFiles = true;     // if true, the raw and csv files will be split after each given timespan
    const size_t maxSecondsPerFile = 3600; // used if splitLargeFiles is true
    const String filePrefix;               // file name prefix (containing id and stuff)

    Config()
        : filePrefix("test_unit_")
    {}
};

#endif

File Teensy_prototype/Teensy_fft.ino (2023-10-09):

#include <Audio.h>
#include <Wire.h>
#include <SPI.h>
#include <SD.h>
#include <SerialFlash.h>
#include <utility/imxrt_hw.h>

void setI2SFreq(int freq) {
  // PLL between 27*24 = 648MHz und 54*24=1296MHz
  int n1 = 4; //SAI prescaler 4 => (n1*n2) = multiple of 4
  int n2 = 1 + (24000000 * 27) / (freq * 256 * n1);
  double C = ((double)freq * 256 * n1 * n2) / 24000000;
  int c0 = C;
  int c2 = 10000;
  int c1 = C * c2 - (c0 * c2);
  set_audioClock(c0, c1, c2, true);
  CCM_CS1CDR = (CCM_CS1CDR & ~(CCM_CS1CDR_SAI1_CLK_PRED_MASK | CCM_CS1CDR_SAI1_CLK_PODF_MASK))
       | CCM_CS1CDR_SAI1_CLK_PRED(n1-1) // &0x07
       | CCM_CS1CDR_SAI1_CLK_PODF(n2-1); // &0x3f 
}

const int sample_rate = 44100;
uint16_t max_amplitude;                   //highest signal in spectrum              
uint16_t max_freq_Index;
float speed_conversion = (sample_rate/1024)/44.0;
int input;
int mic_gain = 16;

AudioAnalyzeFFT1024      fft1024;      
AudioAmplifier           amp1;           
AudioAnalyzePeak         peak1;          
AudioMixer4              mixer;

AudioInputI2S            mic;           
AudioOutputI2S           headphone;           
AudioConnection          patchCord1(mic, 0, mixer, 0);
AudioControlSGTL5000     sgtl5000_1;     
AudioConnection          patchCord3(mic, amp1);
AudioConnection          patchCord4(amp1, 0, fft1024, 0);
AudioConnection          patchCord5(mixer, 0, peak1, 0);
AudioConnection          patchCord6(mixer, 0, headphone, 0);
AudioConnection          patchCord7(mixer, 0, headphone, 1);


void setup() {
  setI2SFreq(sample_rate);

  // Audio connections require memory to work.  For more
  // detailed information, see the MemoryAndCpuUsage example
  AudioMemory(60);

  // Enable the audio shield, select input, and enable output
  sgtl5000_1.enable();
  sgtl5000_1.inputSelect(AUDIO_INPUT_MIC);
  sgtl5000_1.micGain(mic_gain); 
  //sgtl5000_1.lineInLevel(0);
  sgtl5000_1.volume(.5);

  amp1.gain(1);

  fft1024.windowFunction(AudioWindowHanning1024);

  pinMode(PIN_A8, OUTPUT);
  digitalWrite(PIN_A8, LOW); 

  Serial.begin(1000000);
}


void loop() {

  if (Serial.available() > 0) {
    input = Serial.read();

    if(input==0){
      mic_gain--;
    }
    if(input==1){
      mic_gain++;
    }
    mic_gain = max(0, min(63, mic_gain));
    sgtl5000_1.micGain(mic_gain);
  }

  uint32_t i;
  // uint16_t test[51];
  // for(i = 0; i <= 50; i++){
  //   if(i==10){
  //     test[i] = 40;
  //   }else{
  //     test[i] = i;
  //   }
    
  // }


  if(fft1024.available())
  {
    // output spectrum
    for(i = 0; i <= 511; i++)
    {
      Serial.print((int16_t)(fft1024.read(i) * 1000));

      
      //Serial.write((byte*)&test, sizeof(test));

      // Serial.write(lowByte(test));
      // Serial.write(highByte(test));

      Serial.print(",");
    }
                            
    // detect highest frequency
    max_amplitude = 0;
    max_freq_Index = 0;

    for(i = 0; i < 512; i++) {    
      if ((fft1024.output[i] > 5) & (fft1024.output[i] > max_amplitude)) {
        max_amplitude = fft1024.output[i];        //remember highest amplitude
        max_freq_Index = i;                    //remember frequency index
      }
    }
    Serial.print(max_freq_Index);
    Serial.print(",");


    // detect clipping / overall loudeness
    if(peak1.available()){
      Serial.print(peak1.read());
    }else{
      Serial.print("");
    }
    Serial.print(",");
    Serial.print(mic_gain);
    
    
    Serial.println("");
  }

}

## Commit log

2023-06-27 Hardware Rev. 1
    [BOM.xlsx, LNA_LPF.kicad_sch, Output.kicad_sch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]
2023-08-12 PCB v2
    [BOM_Radar_Amp_v2.xlsx, Radar_Amp_v2.csv, Radar_Amp_v2.kicad_pcb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]
2023-10-08 variable sample rate; transmit full FFT spectrum
2023-10-10 README for teensy prototype
2023-10-11 switch to 32bit Audio library
2023-10-17 correction for I-Q imbalance
    [FFT_visualisation.pde]
2023-10-21 correct IQ axis; new zoom behavior
    [FFT_visualisation.pde]
2023-10-21 corrected zoom behaviour in IQ graph
    [FFT_visualisation.pde]
2023-10-26 write to SD with better format; noise while writing to SD; set time from RTC or computer
    [FFT_visualisation.pde]
2024-01-12 realtime clock sync; filename with timestamp (no overwrite of files); distance from noise floor as amplitude threshold; bins_with_signal as trigger for cars passing by
    [FFT_visualisation.pde]
2024-01-12 moved Hardware folder to different branch
    [BOM.xlsx, BOM_Radar_Amp_v2.xlsx, LNA_LPF.kicad_sch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]
2024-01-12 moved Teensy prototype development into Software folder
2024-09-13 test large file storage (git-lfs)
    [metrics_2024-3-29_12-8-50.csv]
2024-09-18 feature(SD Card): files can now be split and chip will idle until SD card is inserted
2025-01-14 hardware: added sensor mount scad file
    [SensorRadarMount.scad]
